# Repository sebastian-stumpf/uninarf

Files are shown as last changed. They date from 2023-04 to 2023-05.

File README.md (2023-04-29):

# uninarf

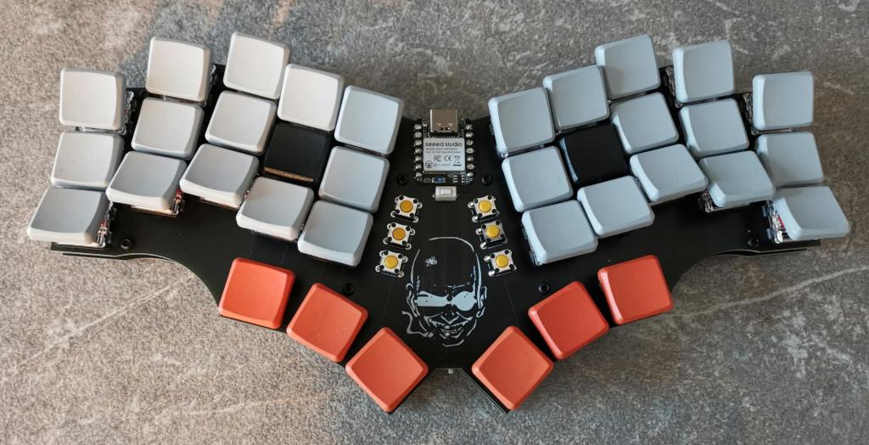
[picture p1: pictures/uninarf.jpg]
uninarf


[More pictures here](https://imgur.com/a/TW84yVa)

## Attention

I'm a hobbyist/amateur at best. So there may be things that aren't optimized. For example
this board doesn't have a ground plane and some edges aren't rounded properly. That being said I've had the files
in the `gerbers/` directory manufactured at JLC with 1.6mm size and they work just fine with the code provided in the
at https://github.com/sebastian-stumpf/zmk-config-uninarf - So if you decide to use this, then please be advised that
I'm not providing any sort of liability and you should exercise some caution.

## BOM

| Quantity  | Item | Comment |
| --- | --- | --- |
| 1 | Seeed XIAO BLE | |
| 1 | 74HC595 SO-16 Shift Register | I used 74HC 595D NXP |
| 42 | 1N4148 SOD123 diodes | |
| 36 | Choc Hotswap Sockets | |
| 6 | Omrom 6mm Tact switches | B3F-1002 |
| 36 | Choc Switches + Keycaps | |
| 8 | M2 Screws and Spacers | |
| 1 | MSK12C02 power switch | |
| 1 | 1 S2B-PH-K-S(LF)(SN) jack | |
| 1 | 3.7v lipo battery | any size will do as long as it fits between the spacers. I've used a 500mAh 403040 |

## Feedback

I'm always happy to hear your opinions about this and if you decide to build this board then please do send me a picture of it.

## Thanks

Big thanks to [GEIST](https://github.com/GEIGEIGEIST) and his [TOTEM](https://github.com/GEIGEIGEIST/TOTEM) where I grabbed the 
xiao ble footprint from. It makes soldering the MCU a lot easier!

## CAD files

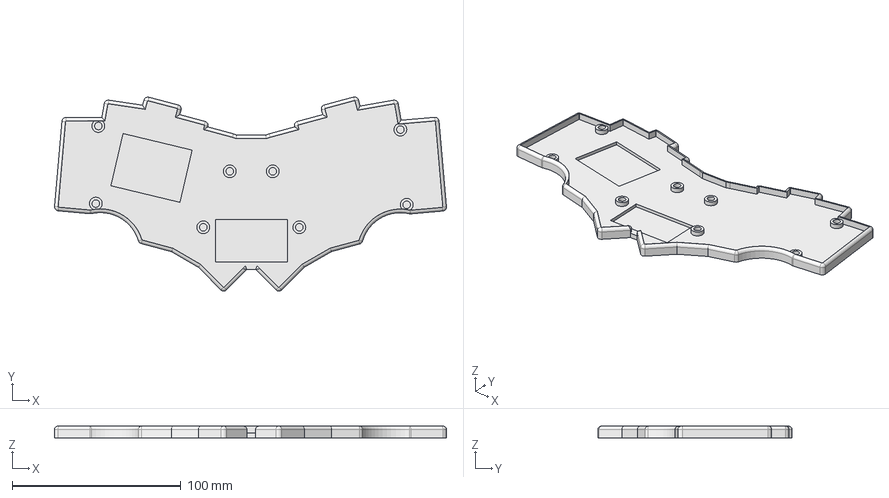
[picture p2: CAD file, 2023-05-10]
experimental/case.FCStd
232.6 x 115.2 x 7.00 mm

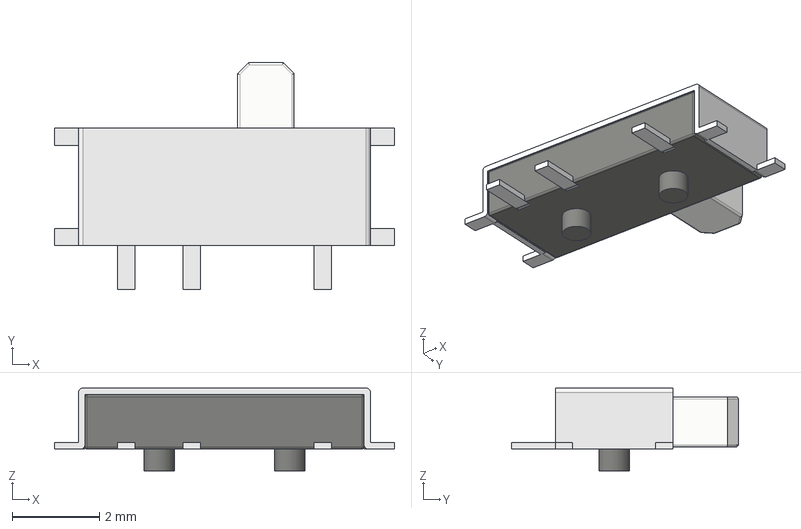
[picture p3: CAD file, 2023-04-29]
pcb/sepp/models/MSK12C02.step
7.80 x 5.20 x 1.90 mm

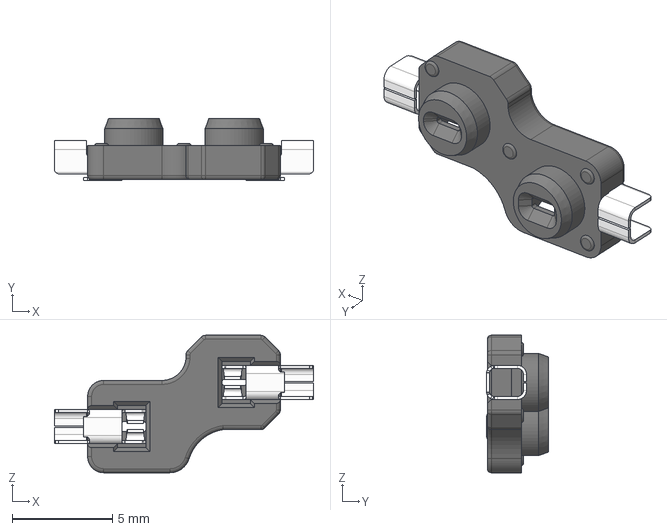
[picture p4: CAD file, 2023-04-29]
pcb/sepp/models/HS_Kailh_Choc.step
12.9 x 3.09 x 6.85 mm
pin x 2
socket

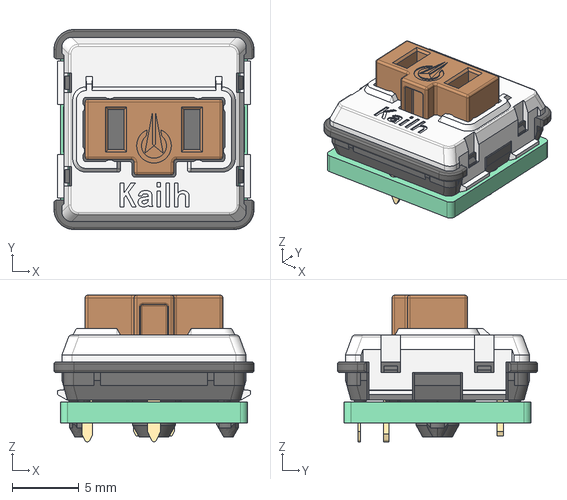
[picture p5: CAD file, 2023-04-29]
pcb/sepp/models/pg1350.step
15.0 x 15.0 x 11.0 mm

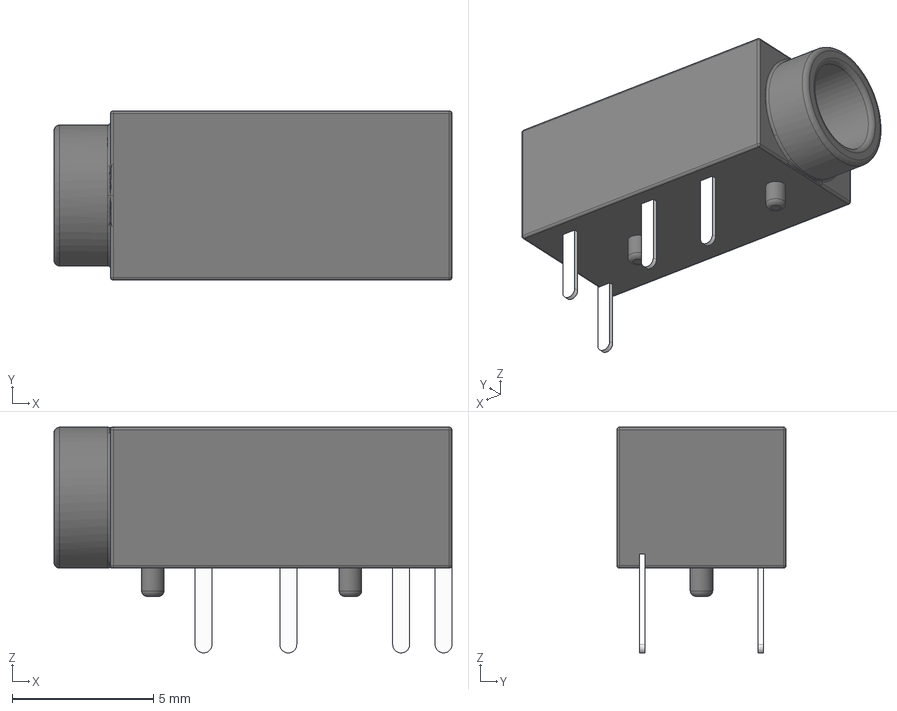
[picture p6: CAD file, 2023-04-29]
pcb/sepp/models/CON_MJ-4PP-9.step
14.1 x 6.00 x 8.00 mm

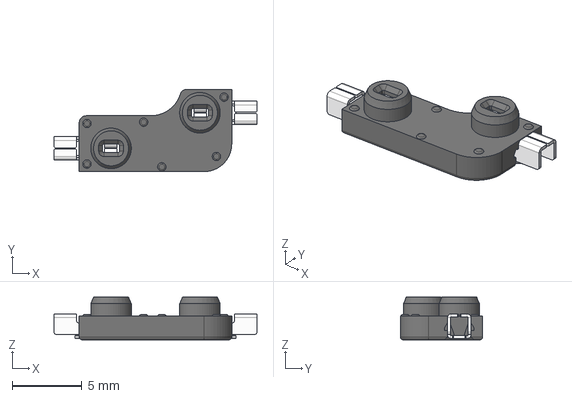
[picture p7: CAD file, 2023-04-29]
pcb/sepp/models/HS_Kailh_MX.step
14.5 x 5.89 x 3.05 mm
Contact x 2

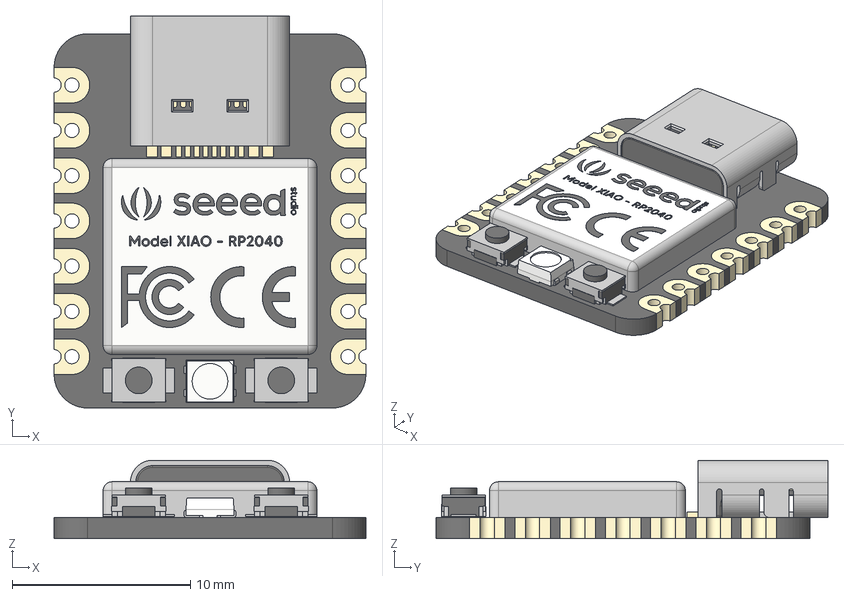
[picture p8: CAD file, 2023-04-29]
pcb/sepp/models/xiao_rp2040.step
17.5 x 22.0 x 4.40 mm
type-c v2
smd_button v3
DOUT
DIN
VSS
VDD
smd_button v3(Mirror)

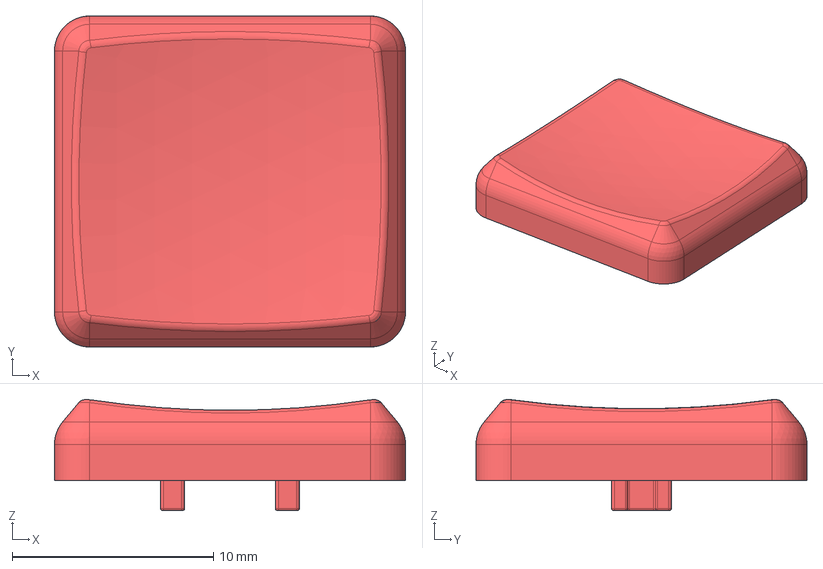
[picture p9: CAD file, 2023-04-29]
pcb/sepp/models/MBK-1u.step
17.4 x 16.4 x 5.52 mm

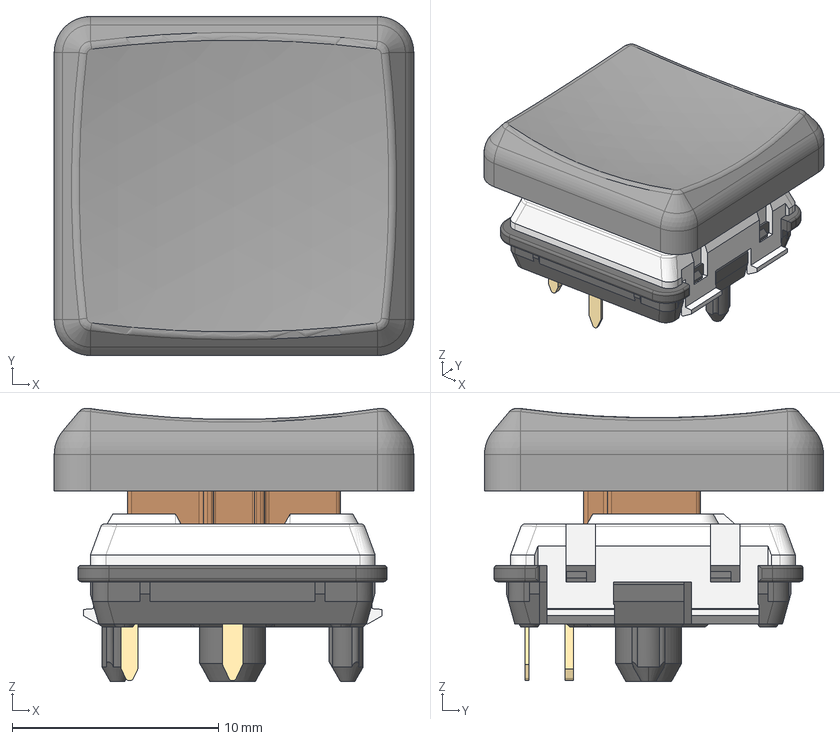
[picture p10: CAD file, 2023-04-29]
pcb/sepp/models/pg1350-mbk.step
17.4 x 16.4 x 13.3 mm
(Unsaved)
Document x 5

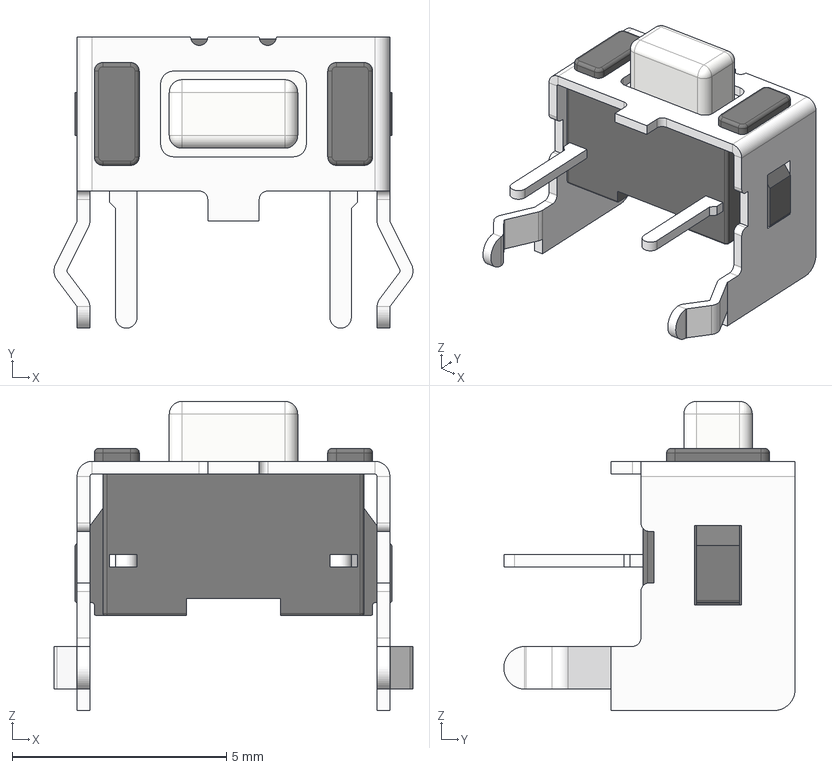
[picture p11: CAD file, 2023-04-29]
pcb/sepp/models/SW_SKHLLC.step
8.38 x 6.80 x 7.22 mm

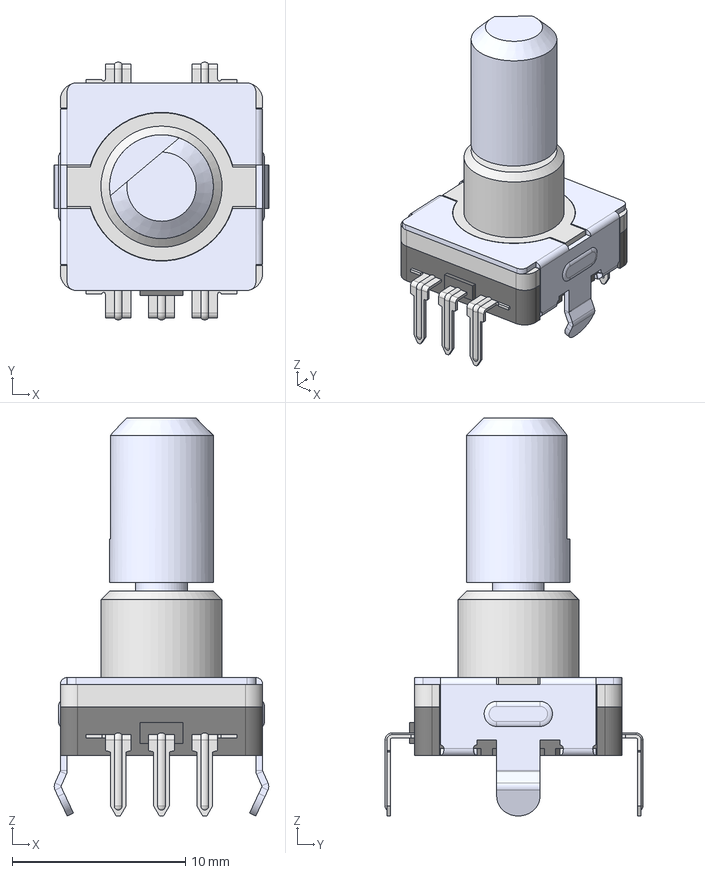
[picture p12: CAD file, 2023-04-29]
pcb/sepp/models/EC11-THT-15F-black.step
12.4 x 14.9 x 23.0 mm
Lb5
15F
EC11-Housing-THT

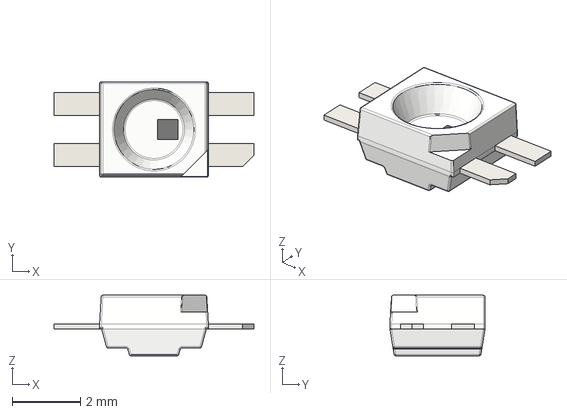
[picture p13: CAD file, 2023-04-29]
pcb/sepp/models/LED_SK6812MINI-E.step
5.88 x 2.80 x 1.78 mm

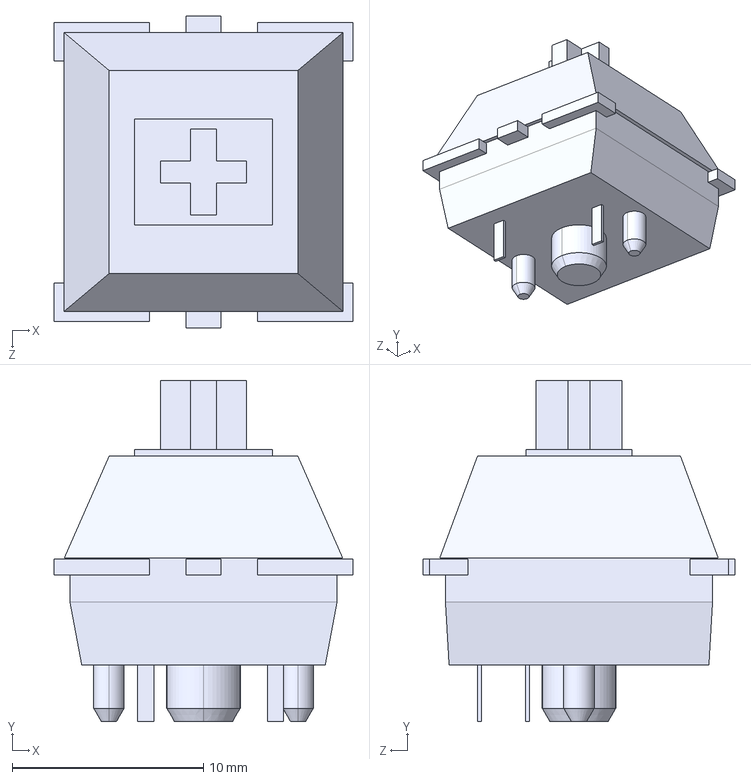
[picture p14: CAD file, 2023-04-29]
pcb/sepp/models/cherry mx.STEP
15.6 x 17.9 x 16.3 mm

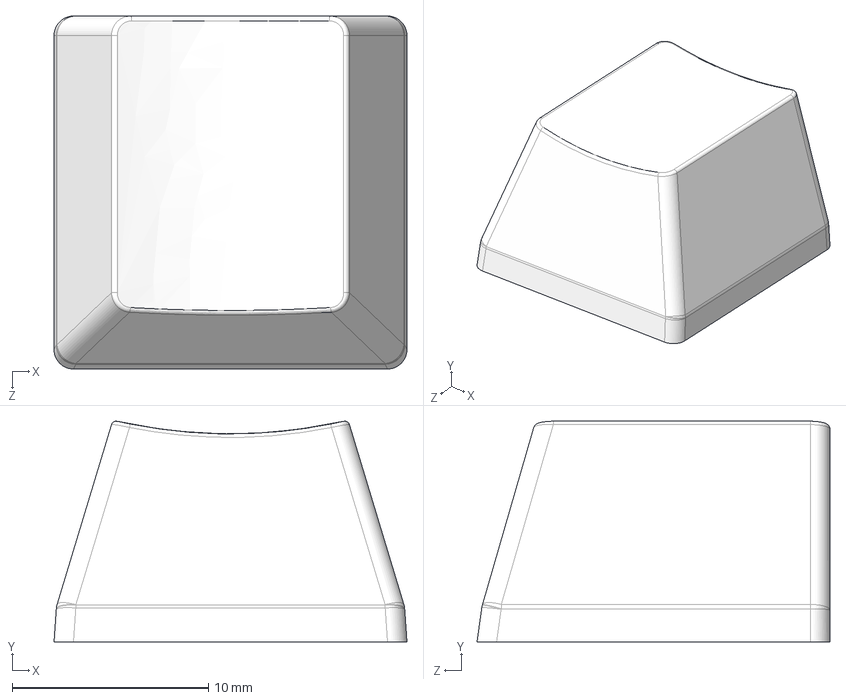
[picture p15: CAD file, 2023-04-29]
pcb/sepp/models/mx_kecap.step
18.0 x 11.3 x 18.0 mm

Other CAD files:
pcb/sepp/models/SW_MSK12C02.step

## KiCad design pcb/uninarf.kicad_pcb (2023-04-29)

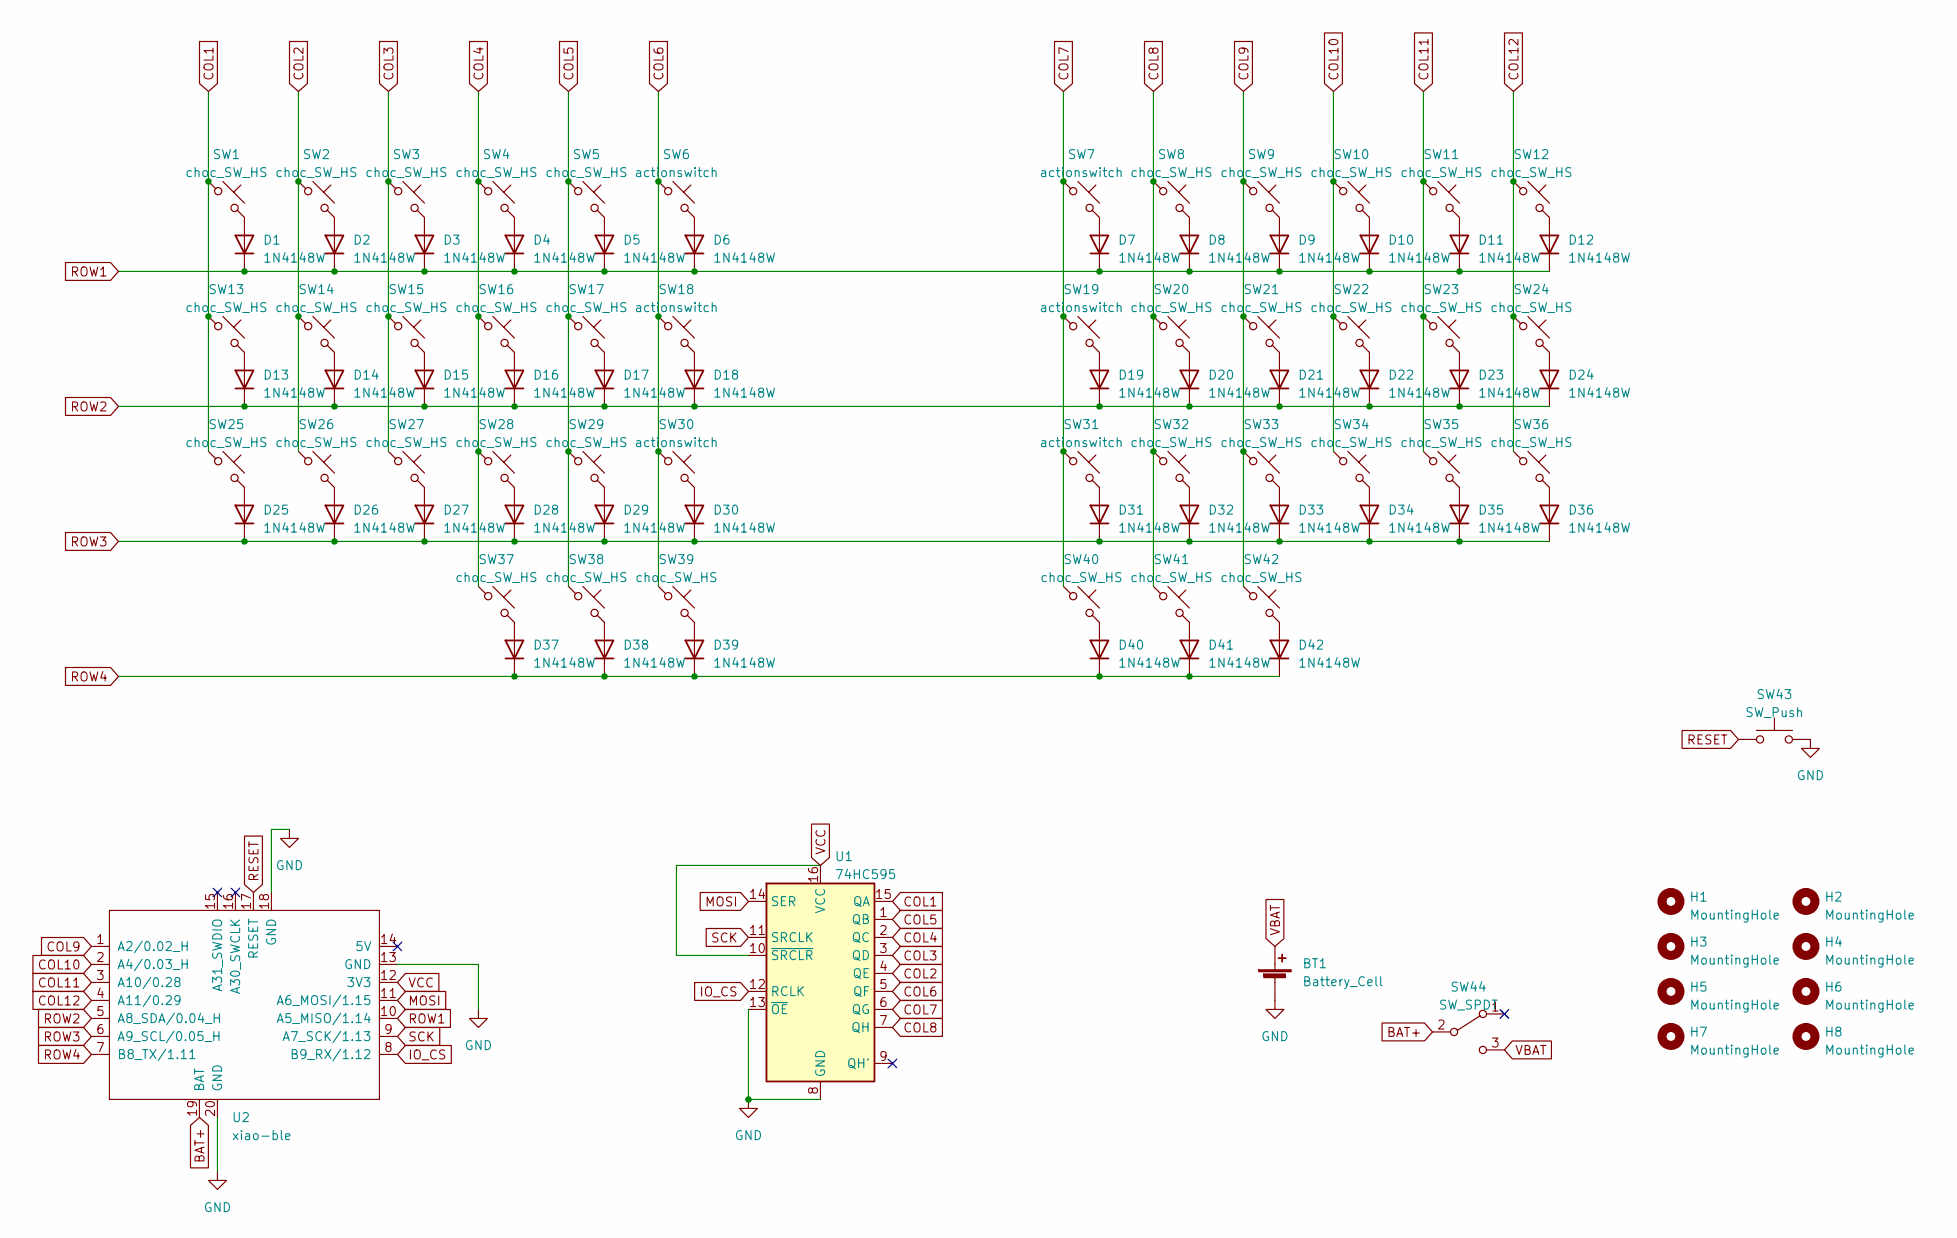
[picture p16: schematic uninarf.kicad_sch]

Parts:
BT1: Battery_Cell; JST_PH_S2B-PH-K_1x02_P2.00mm_Horizontal
D1, D2, D3, D4, D5, D6, D7, D8, D9, D10, D11, D12, D13, D14, D15, D16, D17, D18, D19, D20, D21, D22, D23, D24, D25, D26, D27, D28, D29, D30, D31, D32, D33, D34, D35, D36, D37, D38, D39, D40, D41, D42: 1N4148W; D_SOD-123
H1, H2, H3, H4, H5, H6, H7, H8: MountingHole; MountingHole_2.2mm_M2_DIN965
SW1, SW2, SW3, SW4, SW5, SW8, SW9, SW10, SW11, SW12, SW13, SW14, SW15, SW16, SW17, SW20, SW21, SW22, SW23, SW24, SW25, SW26, SW27, SW28, SW29, SW32, SW33, SW34, SW35, SW36, SW37, SW38, SW39, SW40, SW41, SW42: choc_SW_HS; SW_choc_HS_1u
SW6, SW7, SW18, SW19, SW30, SW31: actionswitch
SW43: SW_Push; ResetSW
SW44: SW_SPDT; switch-MSK-12C02-smd
U1: 74HC595; SOP-16_3.9x9.9mm_P1.27mm
U2: xiao-ble; xiao-ble-smd-cutout-geist

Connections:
BAT+: SW44.2 (B), U2.19 (BAT)
COL1: SW1.1, SW13.1, SW25.1, U1.15 (QA)
COL2: SW2.1, SW14.1, SW26.1, U1.4 (QE)
COL3: SW3.1, SW15.1, SW27.1, U1.3 (QD)
COL4: SW4.1, SW16.1, SW28.1, SW37.1, U1.2 (QC)
COL5: SW5.1, SW17.1, SW29.1, SW38.1, U1.1 (QB)
COL6: SW6.1, SW18.1, SW30.1, SW39.1, U1.5 (QF)
COL7: SW7.1, SW19.1, SW31.1, SW40.1, U1.6 (QG)
COL8: SW8.1, SW20.1, SW32.1, SW41.1, U1.7 (QH)
COL9: SW9.1, SW21.1, SW33.1, SW42.1, U2.1 (A2/0.02_H)
COL10: SW10.1, SW22.1, SW34.1, U2.2 (A4/0.03_H)
COL11: SW11.1, SW23.1, SW35.1, U2.3 (A10/0.28)
COL12: SW12.1, SW24.1, SW36.1, U2.4 (A11/0.29)
GND: BT1.2 (-), SW43.2, U1.8 (GND), U1.13 (~OE), U2.13 (GND), U2.18 (GND), U2.20 (GND)
IO_CS: U1.12 (RCLK), U2.8 (B9_RX/1.12)
MOSI: U1.14 (SER), U2.11 (A6_MOSI/1.15)
unnamed: D1.2 (A), SW1.2
unnamed: D2.2 (A), SW2.2
unnamed: D3.2 (A), SW3.2
unnamed: D4.2 (A), SW4.2
unnamed: D5.2 (A), SW5.2
unnamed: D6.2 (A), SW6.2
unnamed: D7.2 (A), SW7.2
unnamed: D8.2 (A), SW8.2
unnamed: D9.2 (A), SW9.2
unnamed: D10.2 (A), SW10.2
unnamed: D11.2 (A), SW11.2
unnamed: D12.2 (A), SW12.2
unnamed: D13.2 (A), SW13.2
unnamed: D14.2 (A), SW14.2
unnamed: D15.2 (A), SW15.2
unnamed: D16.2 (A), SW16.2
unnamed: D17.2 (A), SW17.2
unnamed: D18.2 (A), SW18.2
unnamed: D19.2 (A), SW19.2
unnamed: D20.2 (A), SW20.2
unnamed: D21.2 (A), SW21.2
unnamed: D22.2 (A), SW22.2
unnamed: D23.2 (A), SW23.2
unnamed: D24.2 (A), SW24.2
unnamed: D25.2 (A), SW25.2
unnamed: D26.2 (A), SW26.2
unnamed: D27.2 (A), SW27.2
unnamed: D28.2 (A), SW28.2
unnamed: D29.2 (A), SW29.2
unnamed: D30.2 (A), SW30.2
unnamed: D31.2 (A), SW31.2
unnamed: D32.2 (A), SW32.2
unnamed: D33.2 (A), SW33.2
unnamed: D34.2 (A), SW34.2
unnamed: D35.2 (A), SW35.2
unnamed: D36.2 (A), SW36.2
unnamed: D37.2 (A), SW37.2
unnamed: D38.2 (A), SW38.2
unnamed: D39.2 (A), SW39.2
unnamed: D40.2 (A), SW40.2
unnamed: D41.2 (A), SW41.2
unnamed: D42.2 (A), SW42.2
RESET: SW43.1, U2.17 (RESET)
ROW1: D1.1 (K), D2.1 (K), D3.1 (K), D4.1 (K), D5.1 (K), D6.1 (K), D7.1 (K), D8.1 (K), D9.1 (K), D10.1 (K), D11.1 (K), D12.1 (K), U2.10 (A5_MISO/1.14)
ROW2: D13.1 (K), D14.1 (K), D15.1 (K), D16.1 (K), D17.1 (K), D18.1 (K), D19.1 (K), D20.1 (K), D21.1 (K), D22.1 (K), D23.1 (K), D24.1 (K), U2.5 (A8_SDA/0.04_H)
ROW3: D25.1 (K), D26.1 (K), D27.1 (K), D28.1 (K), D29.1 (K), D30.1 (K), D31.1 (K), D32.1 (K), D33.1 (K), D34.1 (K), D35.1 (K), D36.1 (K), U2.6 (A9_SCL/0.05_H)
ROW4: D37.1 (K), D38.1 (K), D39.1 (K), D40.1 (K), D41.1 (K), D42.1 (K), U2.7 (B8_TX/1.11)
SCK: U1.11 (SRCLK), U2.9 (A7_SCK/1.13)
VBAT: BT1.1 (+), SW44.3 (C)
VCC: U1.10 (~SRCLR), U1.16 (VCC), U2.12 (3V3)

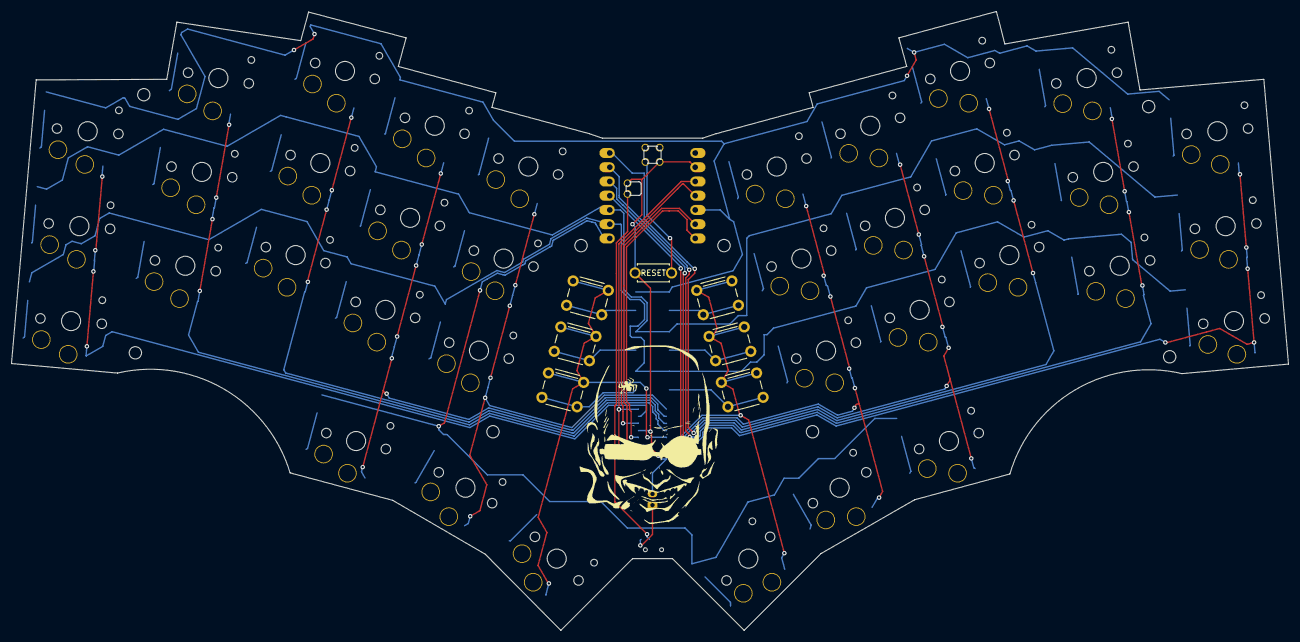
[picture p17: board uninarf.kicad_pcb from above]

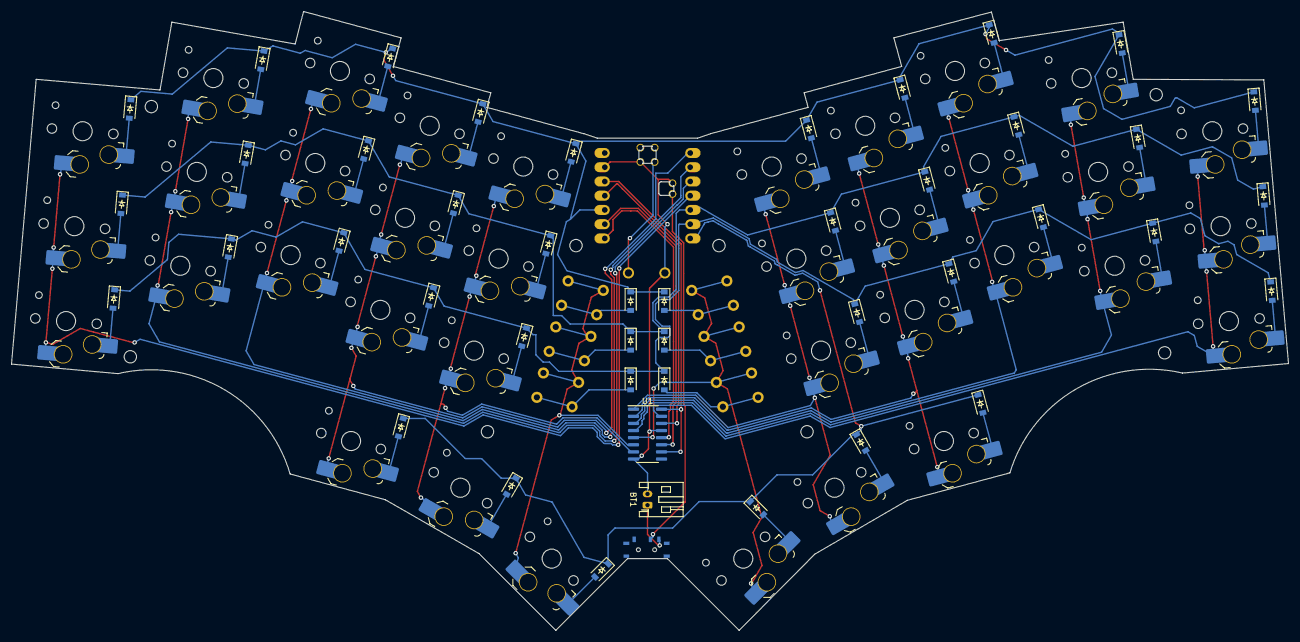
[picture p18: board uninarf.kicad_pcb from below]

Board: 2 copper layers, 227.8 x 110.4 mm, 97 parts (45 on the bottom side), 66 nets.

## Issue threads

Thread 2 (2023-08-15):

Keycaps

jurica, 2023-08-15:
Hi Sebastian,

I wonder what keycaps you are using on this picture: https://github.com/sebastian-stumpf/uninarf/blob/master/pictures/uninarf.jpg
It looks like the first and third row is tilted, but as far as I can tell from the picture the switches are mounted flush.
Would you mind uploading some more pictures of that board or explain how you reached that?

Thanks in advance!
Juri

PS: Sorry for opening an issue for that question but I haven't found any other way contacting you.

sebastian-stumpf, 2023-08-28:
They are mounted via these keycap tilters: https://www.printables.com/model/197363-choc-keycap-tilter

jurica, 2023-08-29:
Thanks for your response!

Closed 2023-08-29.

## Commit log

2023-04-29 expanded bom
2023-05-10 added case
    [case.FCStd]
